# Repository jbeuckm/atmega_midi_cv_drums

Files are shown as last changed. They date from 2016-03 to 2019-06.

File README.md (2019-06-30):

atmega_midi_cv_drums
========================

This is designed to drive drum voice circuits similar to those found in the TR-808.

A CMOS addressable latch (CD4099) generates eight trigger signals. Uses TLV5628 octal DAC to generate eight “accent” trigger signals. All signals are approximately 1ms in duration. Triggers are to the positive rail and accents are scaled by velocity of the MIDI note. Accent signals in the 808 are intended to run 4-14V, so a +/-15V supply would be appropriate here.

Euro power connectors distribute the trigger and accent signals for eight drum voices, using the “gate” and “CV” buss conventions from eurorack. The power distribution daughterboard includes four dual rail-to-rail opamps that scale the DAC output accent signals up to the intended 4-14V range (given +/-15V supply). Each power connector provides power, trigger and accent signals to the connected module.

Assign each voice to a MIDI note number with this sysex message:

```0x77 0x08 0x01 <voice> <MIDI_note> 0xf7```

The voice number depends on which voice is connected to which dac output via the eurorack power style distribution connectors.

![midi schematic](schemo.png)

Power distribution daughterboard:

![power distribution board](eagle/power_cv_distro.png)

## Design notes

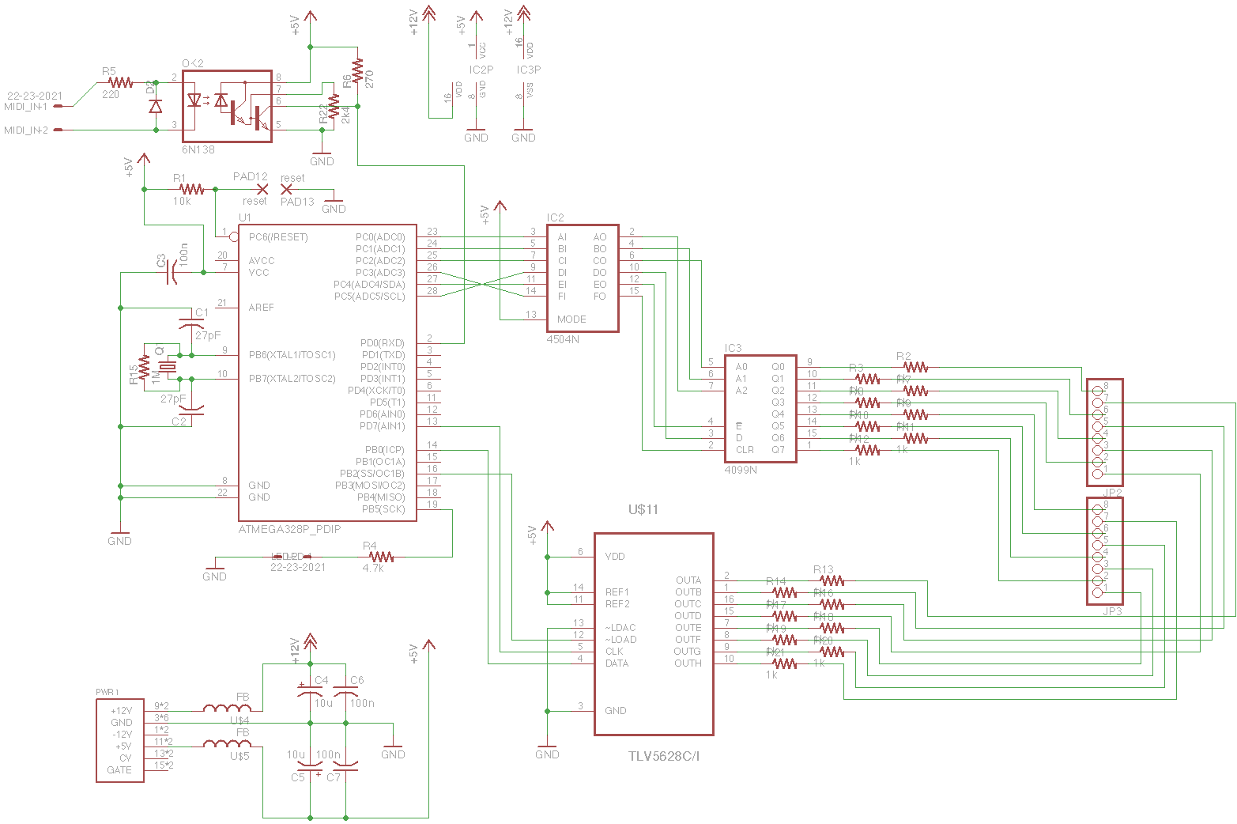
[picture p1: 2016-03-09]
schemo.png

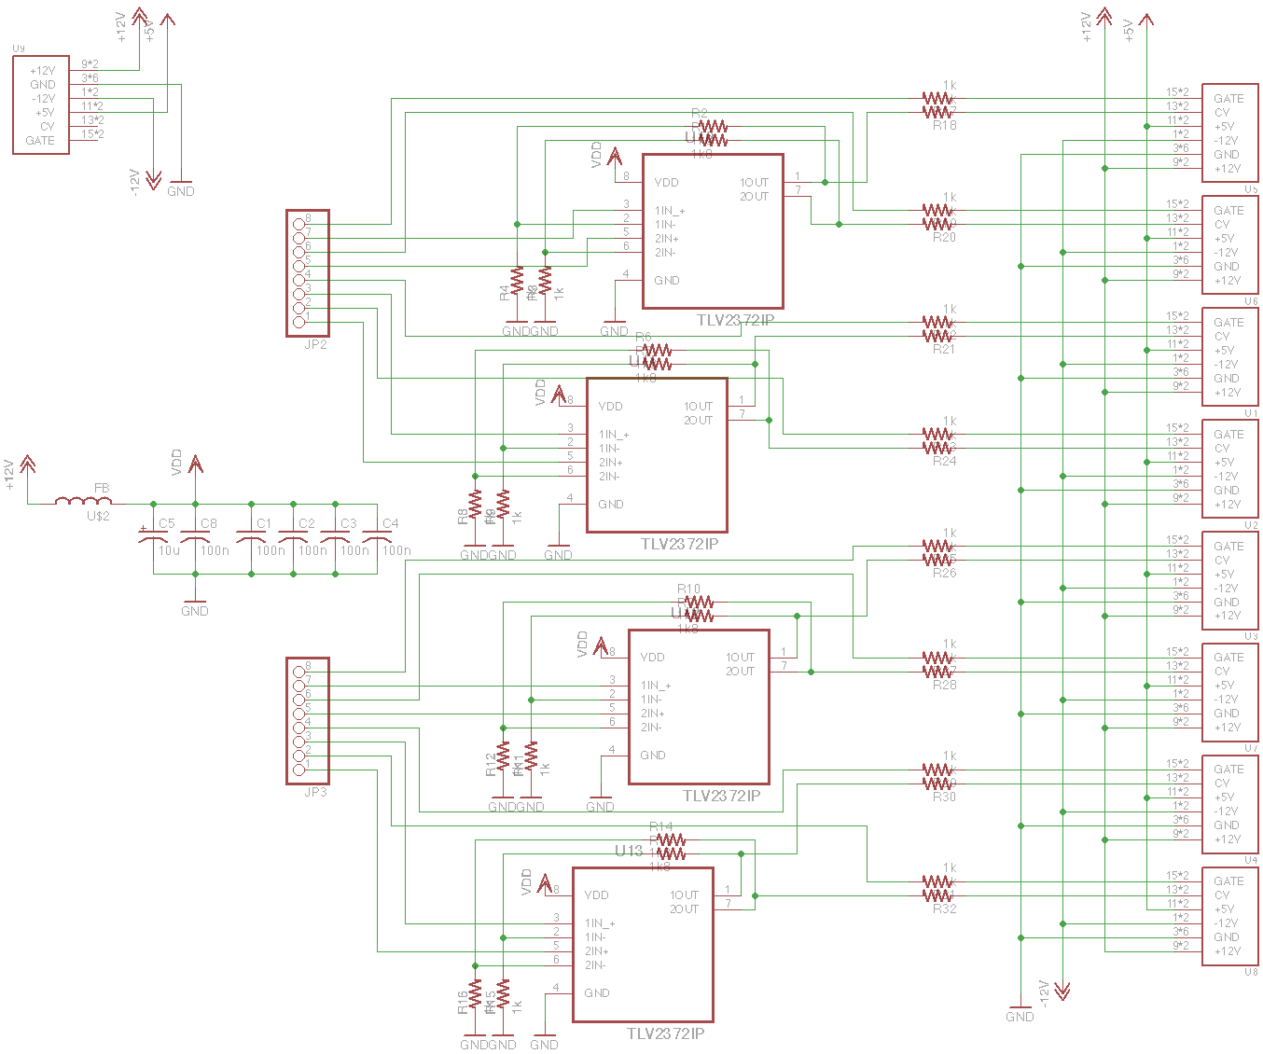
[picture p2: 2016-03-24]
eagle/power_cv_distro.png

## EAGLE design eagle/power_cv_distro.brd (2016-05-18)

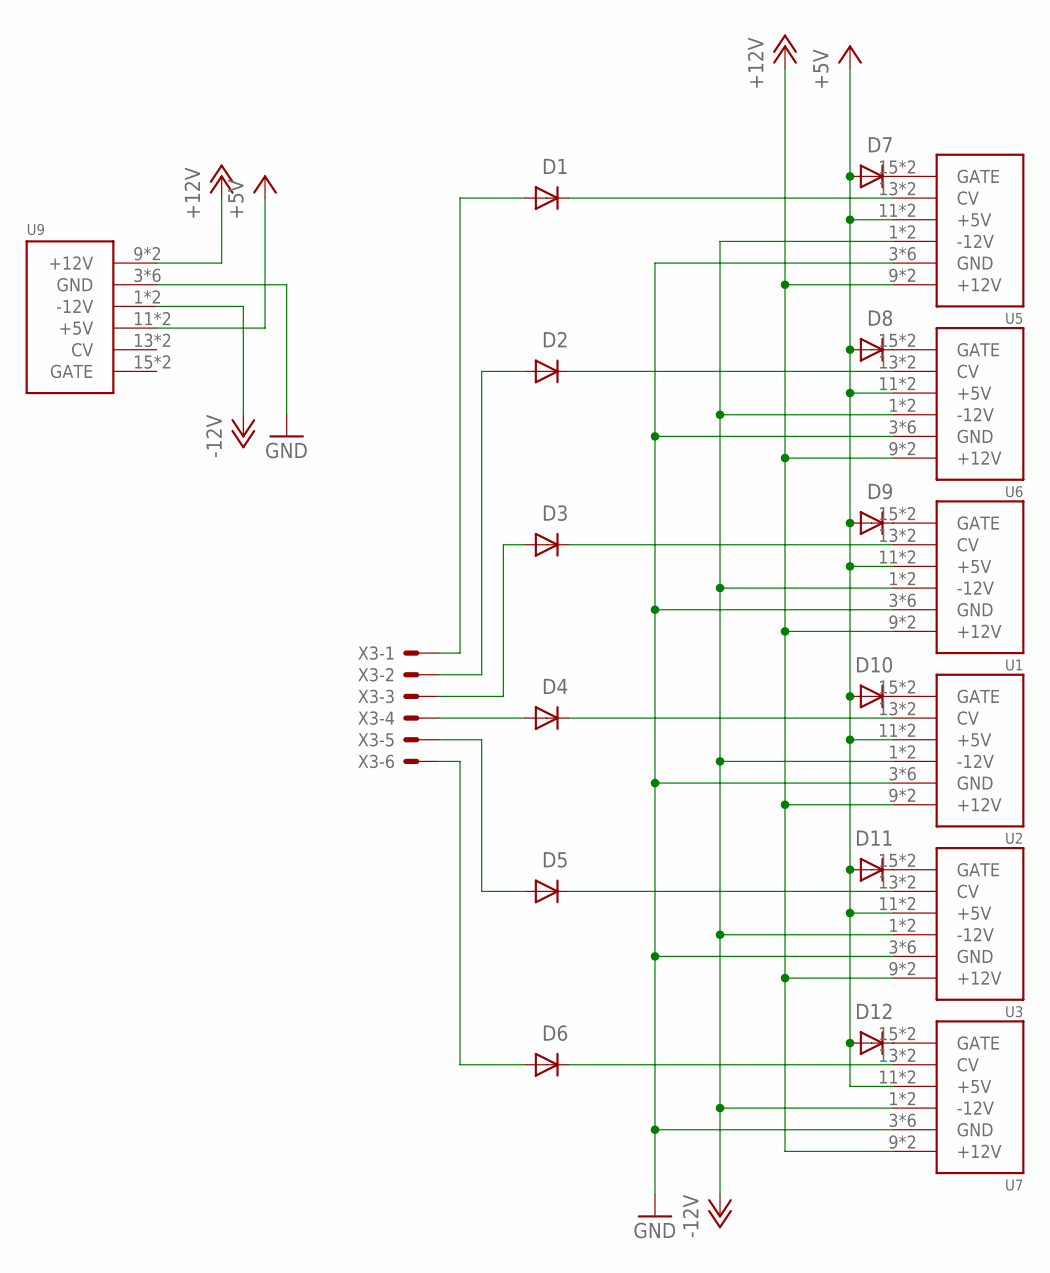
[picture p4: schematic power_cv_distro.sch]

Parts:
D1, D2, D3, D4, D5, D6, D7, D8, D9, D10, D11, D12: 1N4148DO35-7; DO35-7
U1, U2, U3, U5, U6, U7, U9: POWER; POWER_16
X3: 22-23-2061

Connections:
+5V: D7.A, D8.A, D9.A, D10.A, D11.A, D12.A, U1.11 (+5V), U1.12 (+5V), U2.11 (+5V), U2.12 (+5V), U3.11 (+5V), U3.12 (+5V), U5.11 (+5V), U5.12 (+5V), U6.11 (+5V), U6.12 (+5V), U7.11 (+5V), U7.12 (+5V), U9.11 (+5V), U9.12 (+5V)
+12V: U1.9 (+12V), U1.10 (+12V), U2.9 (+12V), U2.10 (+12V), U3.9 (+12V), U3.10 (+12V), U5.9 (+12V), U5.10 (+12V), U6.9 (+12V), U6.10 (+12V), U7.9 (+12V), U7.10 (+12V), U9.9 (+12V), U9.10 (+12V)
-12V: U1.1 (-12V), U1.2 (-12V), U2.1 (-12V), U2.2 (-12V), U3.1 (-12V), U3.2 (-12V), U5.1 (-12V), U5.2 (-12V), U6.1 (-12V), U6.2 (-12V), U7.1 (-12V), U7.2 (-12V), U9.1 (-12V), U9.2 (-12V)
GND: U1.3 (GND), U1.4 (GND), U1.5 (GND), U1.6 (GND), U1.7 (GND), U1.8 (GND), U2.3 (GND), U2.4 (GND), U2.5 (GND), U2.6 (GND), U2.7 (GND), U2.8 (GND), U3.3 (GND), U3.4 (GND), U3.5 (GND), U3.6 (GND), U3.7 (GND), U3.8 (GND), U5.3 (GND), U5.4 (GND), U5.5 (GND), U5.6 (GND), U5.7 (GND), U5.8 (GND), U6.3 (GND), U6.4 (GND), U6.5 (GND), U6.6 (GND), U6.7 (GND), U6.8 (GND), U7.3 (GND), U7.4 (GND), U7.5 (GND), U7.6 (GND), U7.7 (GND), U7.8 (GND), U9.3 (GND), U9.4 (GND), U9.5 (GND), U9.6 (GND), U9.7 (GND), U9.8 (GND)
unnamed: D1.A, X3.1
unnamed: D2.A, X3.2
unnamed: D3.A, X3.3
unnamed: D4.A, X3.4
unnamed: D5.A, X3.5
unnamed: D6.A, X3.6
unnamed: D1.C, U5.13 (CV), U5.14 (CV)
unnamed: D2.C, U6.13 (CV), U6.14 (CV)
unnamed: D3.C, U1.13 (CV), U1.14 (CV)
unnamed: D4.C, U2.13 (CV), U2.14 (CV)
unnamed: D5.C, U3.13 (CV), U3.14 (CV)
unnamed: D6.C, U7.13 (CV), U7.14 (CV)
unnamed: D7.C, U5.15 (GATE), U5.16 (GATE)
unnamed: D8.C, U6.15 (GATE), U6.16 (GATE)
unnamed: D9.C, U1.15 (GATE), U1.16 (GATE)
unnamed: D10.C, U2.15 (GATE), U2.16 (GATE)
unnamed: D11.C, U3.15 (GATE), U3.16 (GATE)
unnamed: D12.C, U7.15 (GATE), U7.16 (GATE)

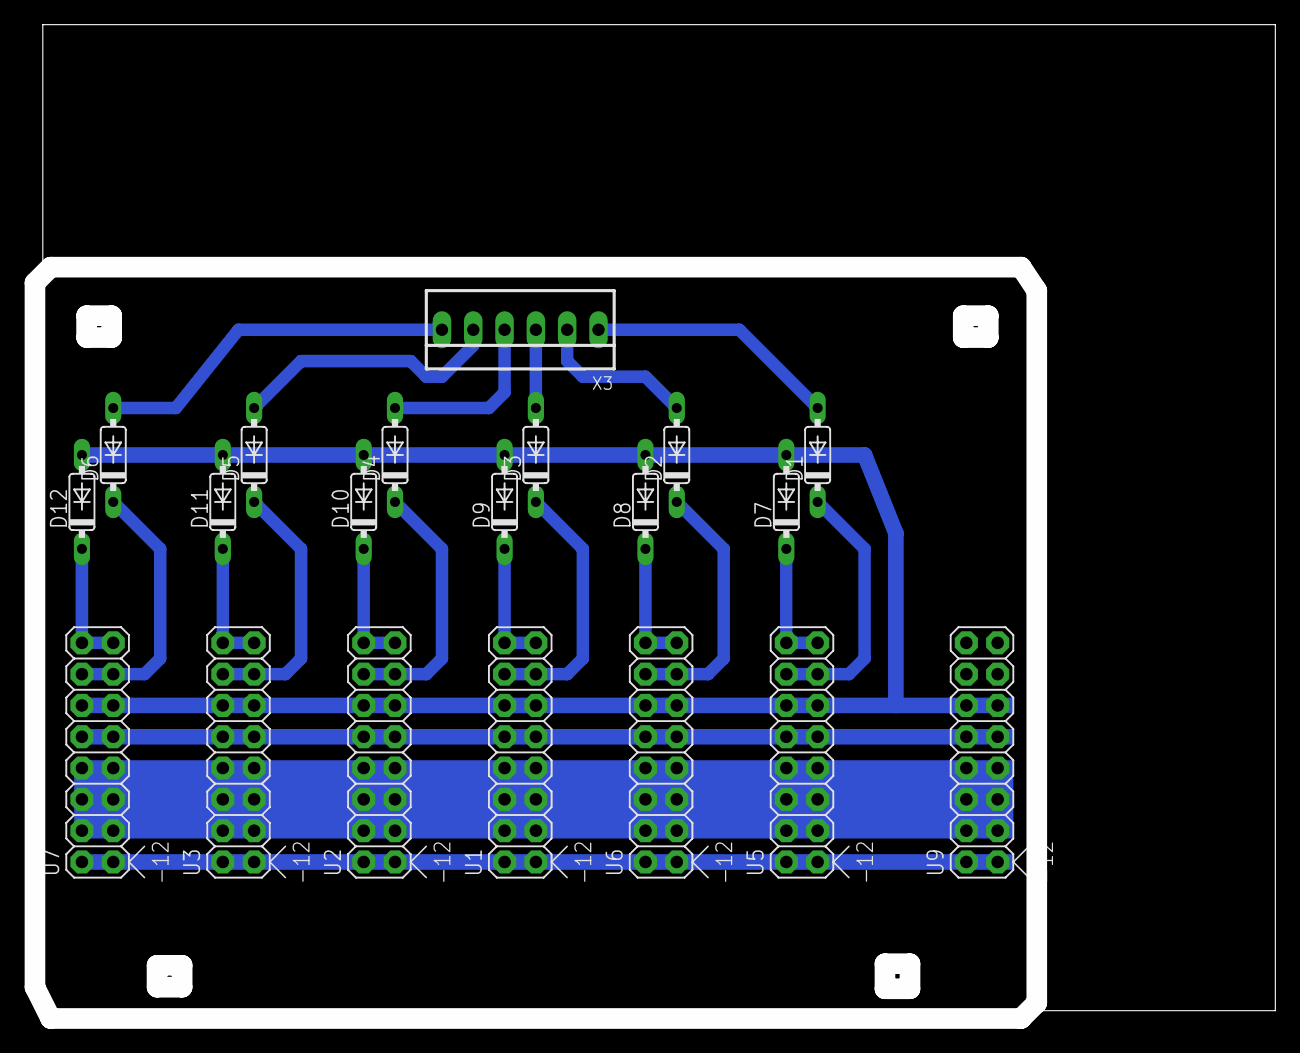
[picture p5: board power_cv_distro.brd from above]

Board: 2 copper layers, 100.6 x 80.6 mm, 20 parts (0 on the bottom side), 22 nets.

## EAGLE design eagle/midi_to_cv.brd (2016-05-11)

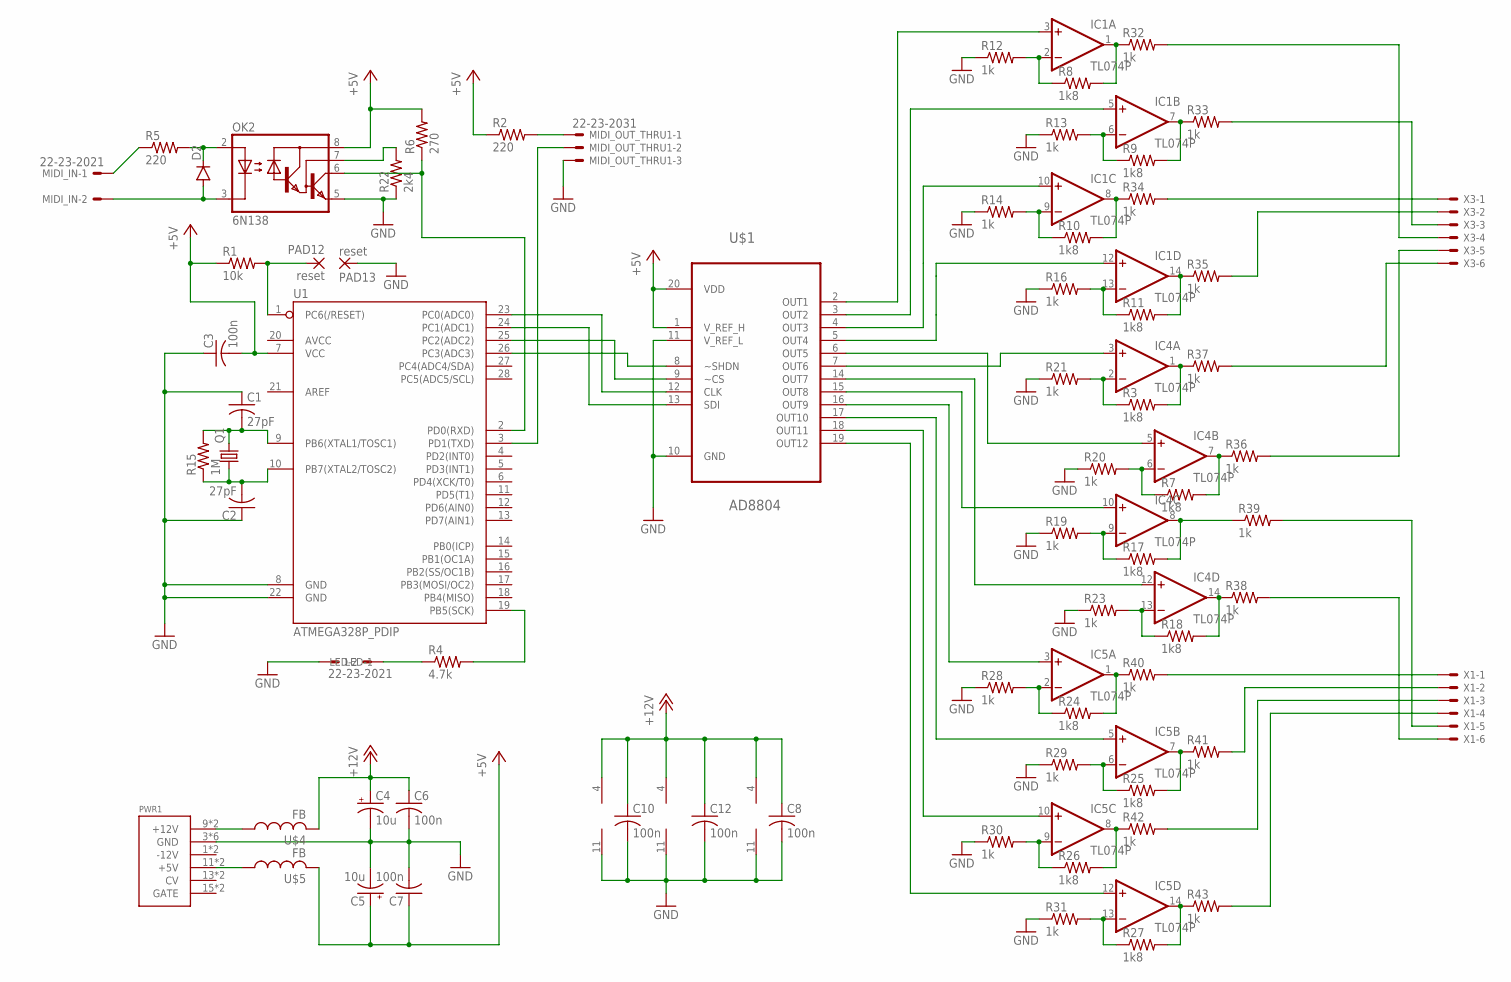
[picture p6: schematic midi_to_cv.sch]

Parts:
C1, C2: 27pF; C025-040X050
C3: 100n; C025-040X050
C4, C5: 10u; B45181A
C6, C7: 100n; C050-024X044
C8, C10, C12: 100n; C025-024X044
D2: DIODE1N4148; DIODE-1N4148
IC1, IC4, IC5: TL074P; DIL14
LED: 22-23-2021
MIDI_IN: 22-23-2021
MIDI_OUT_THRU1: 22-23-2031
OK2: 6N138; DIL08
PAD12, PAD13: reset; 2,54/0,9
PWR1: POWER; POWER_16
Q1: CRYSTALHC49U-V; HC49U-V
R1: 10k; 0207/10
R2: 220; 0207/10
R3, R7, R8, R9, R10, R11, R17, R18, R24, R25, R26, R27: 1k8; 0204V
R4: 4.7k; 0207/10
R5: 220; 0204/7
R6: 270; 0207/10
R12, R13, R14, R16, R19, R20, R21, R23, R28, R29, R30, R31, R33, R34, R35, R41, R42: 1k; 0204/5
R15: 1M; 0207/10
R22: 2k4; 0207/10
R32, R36, R37, R38, R39, R40, R43: 1k; 0204/7
U1: ATMEGA328P_PDIP; DIL28-3
U$1: AD8804; DIL20
U$4, U$5: FB
X1, X3: 22-23-2061

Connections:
+5V: C3.2, C5.+, C7.1, OK2.8 (VCC), R1.1, R2.1, R6.2, U1.7 (VCC), U$1.1 (V_REF_H), U$1.20 (VDD), U$5.P$2 (2)
+12V: C4.+, C6.1, C8.1, C10.1, C12.1, IC1.4 (V+), IC4.4 (V+), IC5.4 (V+), U$4.P$2 (2)
GND: C1.1, C2.1, C3.1, C4.-, C5.-, C6.2, C7.2, C8.2, C10.2, C12.2, IC1.11 (V-), IC4.11 (V-), IC5.11 (V-), LED.1, MIDI_OUT_THRU1.3, OK2.5 (GND), PAD13.1, PWR1.3 (GND), PWR1.4 (GND), PWR1.5 (GND), PWR1.6 (GND), PWR1.7 (GND), PWR1.8 (GND), R12.1, R13.1, R14.1, R16.1, R19.1, R20.1, R21.1, R22.1, R23.1, R28.1, R29.1, R30.1, R31.1, U1.8 (GND), U1.22 (GND), U$1.10 (GND), U$1.11 (V_REF_L)
unnamed: PAD12.1, R1.2, U1.1 (PC6(/RESET))
unnamed: PWR1.9 (+12V), PWR1.10 (+12V), U$4.P$1 (1)
unnamed: U1.26 (PC3(ADC3)), U$1.8 (~SHDN)
unnamed: C1.2, Q1.2, R15.2, U1.9 (PB6(XTAL1/TOSC1))
unnamed: C2.2, Q1.1, R15.1, U1.10 (PB7(XTAL2/TOSC2))
unnamed: U1.25 (PC2(ADC2)), U$1.9 (~CS)
unnamed: U1.23 (PC0(ADC0)), U$1.12 (CLK)
unnamed: U1.24 (PC1(ADC1)), U$1.13 (SDI)
unnamed: MIDI_OUT_THRU1.1, R2.2
unnamed: R4.2, U1.19 (PB5(SCK))
unnamed: LED.2, R4.1
unnamed: MIDI_OUT_THRU1.2, U1.3 (PD1(TXD))
unnamed: IC1.2 (-IN), R8.1, R12.2
unnamed: IC1.9 (-IN), R10.1, R14.2
unnamed: IC1.6 (-IN), R9.1, R13.2
unnamed: IC4.7 (OUT), R7.2, R36.1
unnamed: D2.A, MIDI_IN.2, OK2.3 (C)
unnamed: D2.C, OK2.2 (A), R5.2
unnamed: MIDI_IN.1, R5.1
unnamed: OK2.6 (VO), R6.1, U1.2 (PD0(RXD))
unnamed: IC1.13 (-IN), R11.1, R16.2
unnamed: IC4.8 (OUT), R17.2, R39.1
unnamed: IC4.14 (OUT), R18.2, R38.1
unnamed: IC4.9 (-IN), R17.1, R19.2
unnamed: R34.2, X3.1
unnamed: IC1.3 (+IN), U$1.2 (OUT1)
unnamed: IC1.5 (+IN), U$1.3 (OUT2)
unnamed: IC1.10 (+IN), U$1.4 (OUT3)
unnamed: IC1.12 (+IN), U$1.5 (OUT4)
unnamed: IC4.6 (-IN), R7.1, R20.2
unnamed: IC4.2 (-IN), R3.1, R21.2
unnamed: IC4.5 (+IN), U$1.6 (OUT5)
unnamed: IC4.3 (+IN), U$1.7 (OUT6)
unnamed: IC4.12 (+IN), U$1.14 (OUT7)
unnamed: IC4.10 (+IN), U$1.15 (OUT8)
unnamed: IC4.13 (-IN), R18.1, R23.2
unnamed: IC4.1 (OUT), R3.2, R37.1
unnamed: R35.2, X3.2
unnamed: R33.2, X3.3
unnamed: R32.2, X3.4
unnamed: IC5.3 (+IN), U$1.16 (OUT9)
unnamed: IC5.5 (+IN), U$1.17 (OUT10)
unnamed: IC5.10 (+IN), U$1.18 (OUT11)
unnamed: IC5.12 (+IN), U$1.19 (OUT12)
unnamed: IC5.2 (-IN), R24.1, R28.2
unnamed: IC5.6 (-IN), R25.1, R29.2
unnamed: IC5.9 (-IN), R26.1, R30.2
unnamed: IC5.13 (-IN), R27.1, R31.2
unnamed: IC5.1 (OUT), R24.2, R40.1
unnamed: IC5.7 (OUT), R25.2, R41.1
unnamed: IC5.8 (OUT), R26.2, R42.1
unnamed: IC5.14 (OUT), R27.2, R43.1
unnamed: IC1.1 (OUT), R8.2, R32.1
unnamed: IC1.7 (OUT), R9.2, R33.1
unnamed: IC1.8 (OUT), R10.2, R34.1
unnamed: IC1.14 (OUT), R11.2, R35.1
unnamed: R36.2, X3.5
unnamed: R37.2, X3.6
unnamed: R40.2, X1.1
unnamed: OK2.7 (VB), R22.2
unnamed: R41.2, X1.2
unnamed: PWR1.11 (+5V), PWR1.12 (+5V), U$5.P$1 (1)
unnamed: R42.2, X1.3
unnamed: R43.2, X1.4
unnamed: R39.2, X1.5
unnamed: R38.2, X1.6

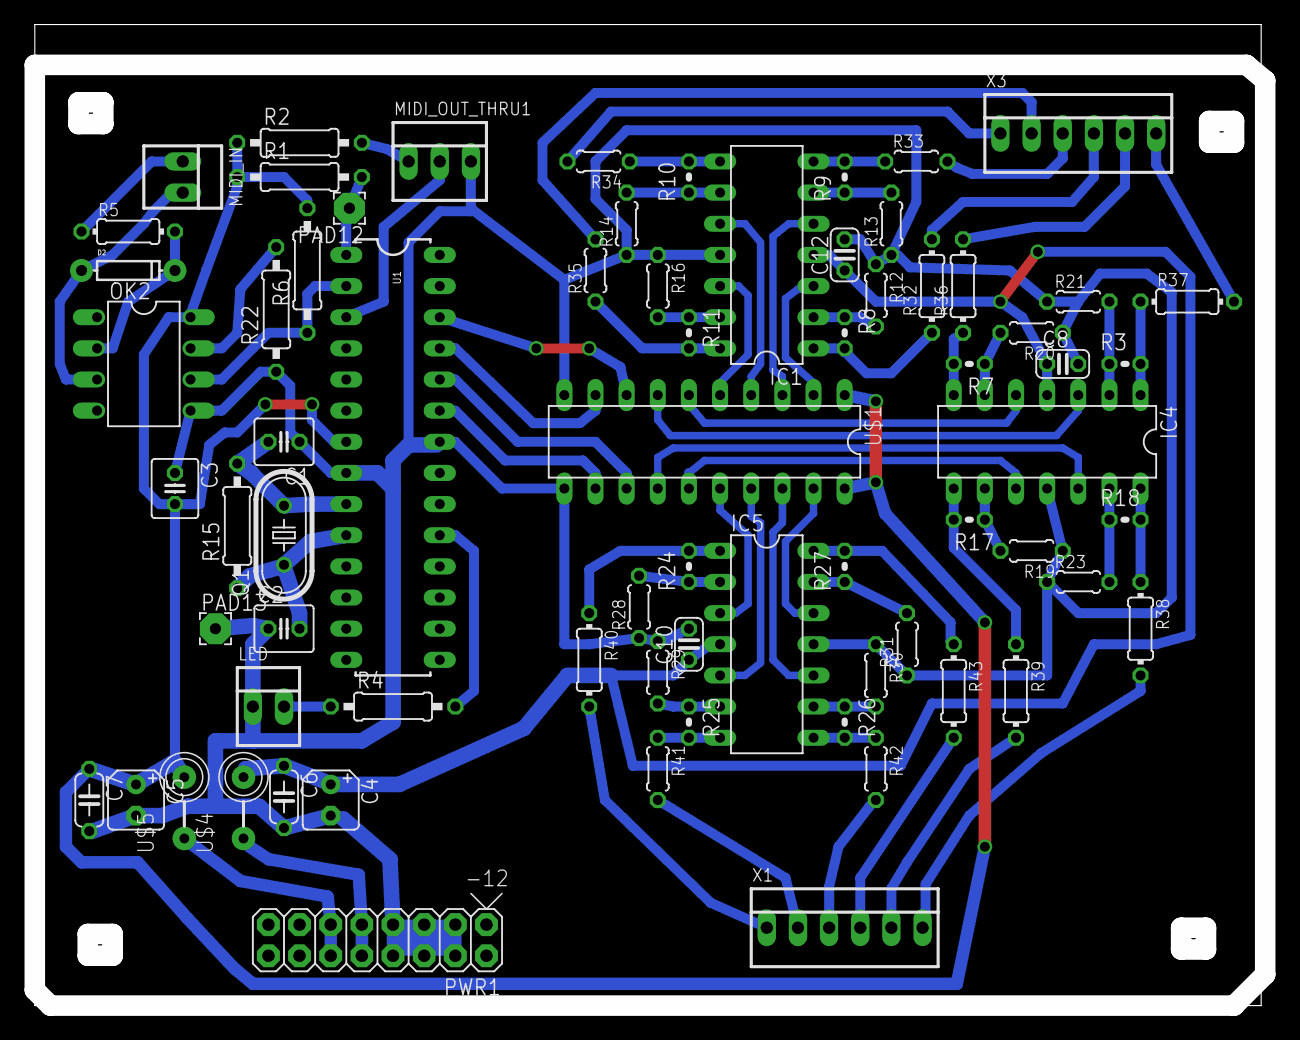
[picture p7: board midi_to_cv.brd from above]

Board: 2 copper layers, 100.0 x 80.0 mm, 71 parts (0 on the bottom side), 69 nets.

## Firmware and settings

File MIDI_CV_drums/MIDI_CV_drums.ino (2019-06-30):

#include <TLV5628.h>
#include <AD8804.h>
#include <MIDI.h>
#include <EEPROM.h>

#define CLK_PIN A0
#define SDI_PIN A1
#define CS_PIN A2
#define SHDN_PIN A3

#define GATE_LED 13

#define UNASSIGNED 127

AD8804 velocityDAC(CLK_PIN, SDI_PIN, CS_PIN, SHDN_PIN);

byte noteMap[128];

void loadNoteMap() {
  // clear initial map
  for (int i=0; i<128; i++) {
    noteMap[i] = UNASSIGNED;
  }
  // read map values
  for (int i=0; i<12; i++) {
    byte noteNumber = EEPROM.read(i);
    noteMap[noteNumber] = i;
  }
}

void saveMapping(byte dacChannel, byte noteNumber) {
  byte oldNoteNumber = EEPROM.read(dacChannel);
  noteMap[oldNoteNumber] = UNASSIGNED;
  noteMap[noteNumber] = dacChannel;
  EEPROM.write(dacChannel, noteNumber);
}

byte voice_gates[] = { 0, 0, 0, 0, 0, 0, 0, 0, 0, 0, 0, 0 };
byte voice_accents[] = { 0, 0, 0, 0, 0, 0, 0, 0, 0, 0, 0, 0 };

MIDI_CREATE_DEFAULT_INSTANCE();


void handleSystemExclusive(byte message[], unsigned size) {

  if (message[1] != 0x77) return;      // manufacturer ID
  if (message[2] != 0x08) return;      // model ID
  if (message[3] != 0x01) return;  // device ID

  byte dacIndex = message[4];
  byte midiNote = message[5];

  saveMapping(dacIndex, midiNote);
}


void handleNoteOn(byte channel, byte pitch, byte velocity)
{
  byte dacChannel = noteMap[pitch];
  if (dacChannel == UNASSIGNED) {
    return;
  }

  digitalWrite(GATE_LED, HIGH);

  voice_gates[dacChannel] = 2;
  voice_accents[dacChannel] = velocity << 1;
}


int i;

ISR(TIMER1_COMPA_vect) {
  for (i=0; i<12; i++) {
    
    if (voice_gates[i] > 1) {
      velocityDAC.setValue(i, voice_accents[i]);
      voice_gates[i] -= 1;
    }
    else if (voice_gates[i] == 1) {
      velocityDAC.setValue(i, 0);
      voice_gates[i] = 0;
      digitalWrite(GATE_LED, LOW);
    }
    
  }
}


// -----------------------------------------------------------------------------

void setup()
{
  loadNoteMap();
  
  pinMode(GATE_LED, OUTPUT);

  MIDI.setHandleNoteOn(handleNoteOn);
  MIDI.setHandleSystemExclusive(handleSystemExclusive);

    cli();//stop interrupts
    
    //set timer1 interrupt at 1kHz
    TCCR1A = 0;// set entire TCCR1A register to 0
    TCCR1B = 0;// same for TCCR1B
    TCNT1  = 0;//initialize counter value to 0;
    // set timer count for 1khz increments
    OCR1A = 1999;// = (16*10^6) / (1000*8) - 1
    // turn on CTC mode
    TCCR1B |= (1 << WGM12);
    // Set CS11 bit for 8 prescaler
    TCCR1B |= (1 << CS11);   
    // enable timer compare interrupt
    TIMSK1 |= (1 << OCIE1A);
    
    sei();//allow interrupts
    
    
    MIDI.begin(10);
}

void loop()
{
  MIDI.read();
}

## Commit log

2016-03-04 starting with files from polysynth
    [midi_to_cv.brd, midi_to_cv.sch]
2016-03-05 level shift then latch cmos gate outs
    [midi_to_cv.brd, midi_to_cv.sch]
2016-03-05 changing to use tlv5628
    [midi_to_cv.brd, midi_to_cv.sch]
2016-03-05 midi uses header
    [midi_to_cv.brd, midi_to_cv.sch]
2016-03-05 will start over with layout
    [midi_to_cv.brd]
2016-03-05 tidying up
    [midi_to_cv.sch]
2016-03-06 starting brd and dac library
    [midi_to_cv.brd, midi_to_cv.sch]
2016-03-06 adding output resistors
    [midi_to_cv.brd, midi_to_cv.sch]
2016-03-07 ribbon connectors with interleaved gate cna cv instead of power connectors
    [midi_to_cv.brd, midi_to_cv.sch]
2016-03-08 connected midi to serial in
    [midi_to_cv.brd, midi_to_cv.sch]
2016-03-08 ever closer to a route
    [midi_to_cv.brd, midi_to_cv.sch]
2016-03-08 96 percent autorouting
    [midi_to_cv.brd, midi_to_cv.sch]
2016-03-09 mid nineties autoroute
    [midi_to_cv.brd, midi_to_cv.sch]
2016-03-09 a manual start
    [midi_to_cv.brd, midi_to_cv.sch]
2016-03-12 wrote pins from schematic
2016-03-12 fixing up class and debugging
    [MIDI_CV_drums.ino]
2016-03-12 cut and gates work
2016-03-13 dac working for note on velocity
2016-03-13 wider traces and starting distro board
    [midi_to_cv.brd, midi_to_cv.sch, power_cv_distro.brd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]
2016-03-19 adding opamps
    [midi_to_cv.brd, midi_to_cv.sch]
2016-03-19 feedbacks in place
    [midi_to_cv.brd, midi_to_cv.sch]
2016-03-19 started routing
    [midi_to_cv.brd, midi_to_cv.sch]
2016-03-19 opamps in
    [power_cv_distro.brd, power_cv_distro.sch]
2016-03-19 half routed
    [power_cv_distro.brd]
2016-03-19 output resistors
    [power_cv_distro.brd, power_cv_distro.sch]
2016-03-19 route tweaked
    [power_cv_distro.brd, power_cv_distro.sch]
2016-03-19 filtering power for scale opamps
    [power_cv_distro.brd, power_cv_distro.sch]
2016-03-19 power distro gcode
    [power_cv_distro.brd]
2016-03-24 reverted to working midi board
    [midi_to_cv.brd, midi_to_cv.sch]
2016-03-24 power distro brd into readme
2016-05-08 created the device for ad8804 12ch dac
    [midi_to_cv.brd, midi_to_cv.sch]
2016-05-08 midi thru
    [midi_to_cv.brd, midi_to_cv.sch]
2016-05-08 first opamps
    [midi_to_cv.brd, midi_to_cv.sch]
2016-05-11 power dist do-over begins
    [power_cv_distro.brd, power_cv_distro.sch]
2016-05-11 power dist to six only
    [power_cv_distro.brd, power_cv_distro.sch]
2016-05-11 fixed molexes and tweaks
    [midi_to_cv.brd, midi_to_cv.sch]
2016-05-11 fourth mounting hole
    [midi_to_cv.brd]
2016-05-18 added layout png
    [power_cv_distro.brd]

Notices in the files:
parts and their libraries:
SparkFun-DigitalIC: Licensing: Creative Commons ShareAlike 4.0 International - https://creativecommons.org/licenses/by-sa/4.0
